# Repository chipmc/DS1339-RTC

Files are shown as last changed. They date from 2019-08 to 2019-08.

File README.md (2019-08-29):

# DS1339 RTC
DS1339 Real Time Clock Module
 
Created with EAGLE v9 - Information here including a free version - https://www.autodesk.com/products/eagle/overview

If you simply want to order this board, here is an OSHPark link: https://oshpark.com/shared_projects/rNxANV7V
 
This is a basic implementation of the Maxim DS1339 Real Time Clock.  The I2C and Interrupt pins are all presented on a 6-pin header.  There is also a 2-pin header to allow for other sources of battery backup power should you not chose to use the CR1225 coin cell on the back.

This is open source hardware, please feel free to use and improve according to the attached license.  This hardware was developed by See Insights LLC for a project sponsored by Jay Ham, Colorado State University - Thank You!

# Related Software Projects

The original library by Shridhar Rajagopal - https://github.com/sridharrajagopal/DSRTCLib

An adaptation of Shridhar's project I made for the Particle platform - https://github.com/chipmc/RTC-Watchdog

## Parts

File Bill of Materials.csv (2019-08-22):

Part | Value | Device | Package | Digikey | Description | DESCRIPTION | DIGI-KEY_PART_NUMBER | DIGI-KEY_PURCHASE_URL | MF | MP | PACKAGE | PROD_ID | SF_SKU | VALUE
CR1225 |  | BATTERY-12MM_SMD | BATTCON_12MM | EBR1225-ND | Battery - Single Cell |  |  |  |  |  |  | BATT-08044 | PRT-10592
J1 |  | CONN_06LOCK | 1X06_LOCK |  | Multi connection point. Often used as Generic Header-pin footprint for 0.1 inch spaced/style header connections
J2 |  | CONN_02 | 1X02 |  | Multi connection point. Often used as Generic Header-pin footprint for 0.1 inch spaced/style header connections
R1 | 4.7k | RESISTOR0805 | 0805 | 311-4.70KCRCT-ND | Generic Resistor Package
R2 | 4.7k | RESISTOR0805 | 0805 | 311-4.70KCRCT-ND | Generic Resistor Package
R3 | 10k | RESISTOR0805 | 0805 | 311-10.0KCRCT-ND | Generic Resistor Package
U1 | DS1339AU | DS1339AU | SOP65P490X110-8N | DS1339U-33+T&RCT-ND |  | Real Time Clock Serial 8-Pin uMAX | DS1339AU+-ND | https://www.digikey.com/product-detail/en/maxim-integrated/DS1339AU-/DS1339AU--ND/3440513 | Maxim Integrated | DS1339AU+ | &amp | MICRO | MAX-8 Maxim
Y1 | ECS-.327-6-17X-TR | ECS-.327-6-17X-TR | XTAL_ECS-.327-6-17X-TR | XC1307CT-ND | Crystal 4-SOJ, 5.50mm pitch | ECX-306X Series 32.768 kHz ±20 ppm 6 pF -40 to +85 °C SMT Tuning Fork Crystal | XC1307CT-ND | https://www.digikey.com/product-detail/en/ecs-inc/ECS-.327-6-17X-TR/XC1307CT-ND/827771 | ECS Inc. | ECS-.327-6-17X-TR | 4-4 ECS International

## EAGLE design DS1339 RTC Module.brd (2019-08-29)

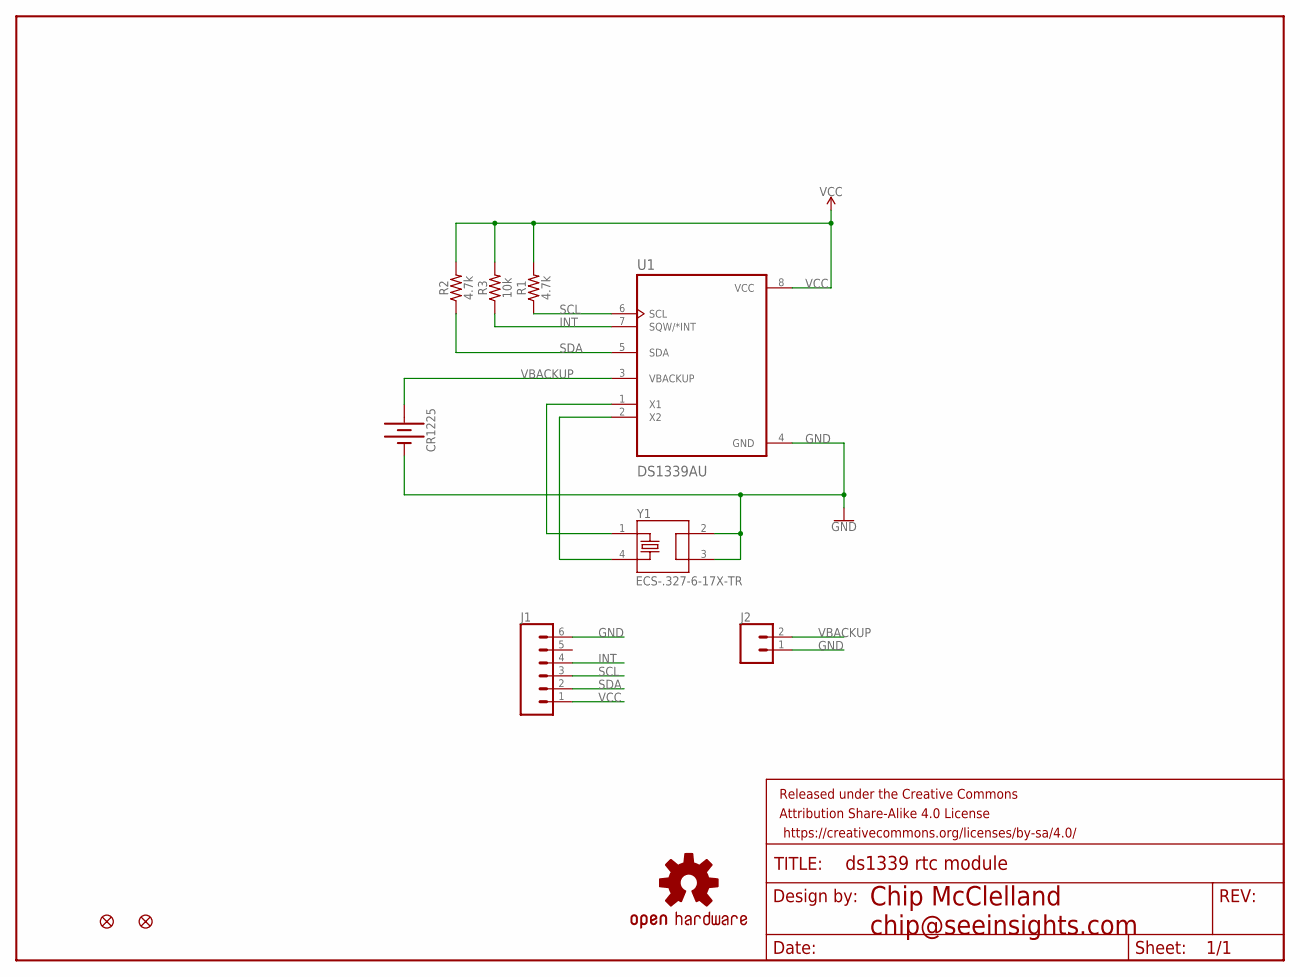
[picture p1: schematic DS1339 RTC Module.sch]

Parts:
CR1225: BATTERY-12MM_SMD; BATTCON_12MM
FD1, FD2: FIDUCIALUFIDUCIAL; FIDUCIAL-MICRO
FRAME1: FRAME-LETTER; CREATIVE_COMMONS
J1: CONN_06LOCK; 1X06_LOCK
J2: CONN_02; 1X02
LOGO1: OSHW-LOGOMINI; OSHW-LOGO-MINI
R1, R2: 4.7k; 0805
R3: 10k; 0805
U1: DS1339AU; SOP65P490X110-8N
Y1: ECS-.327-6-17X-TR; XTAL_ECS-.327-6-17X-TR

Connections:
GND: CR1225.GND (-), J1.6, J2.1, U1.4 (GND), Y1.2, Y1.3
INT: J1.4, R3.1, U1.7 (SQW/*INT)
unnamed: U1.1 (X1), Y1.1
unnamed: U1.2 (X2), Y1.4
SCL: J1.3, R1.1, U1.6 (SCL)
SDA: J1.2, R2.1, U1.5 (SDA)
VBACKUP: CR1225.PWR@2 (+), J2.2, U1.3 (VBACKUP)
VCC: J1.1, R1.2, R2.2, R3.2, U1.8 (VCC)

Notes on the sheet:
Chip McClelland chip@seeinsights.com

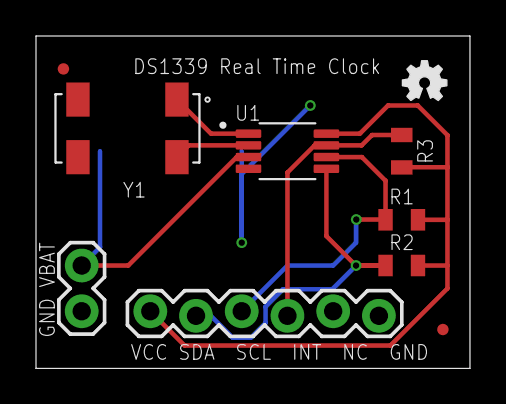
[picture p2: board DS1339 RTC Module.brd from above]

Board: 2 copper layers, 24.1 x 18.5 mm, 12 parts (1 on the bottom side), 8 nets.

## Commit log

2019-08-22 Updated for Publishing
    [DS1339 RTC Module.brd, DS1339 RTC Module.sch]
2019-08-22 Aesthetic Updates
    [DS1339 RTC Module.brd, DS1339 RTC Module.sch]
2019-08-22 Update DS1339 RTC Module.brd
    [DS1339 RTC Module.brd]
2019-08-22 Oops - Flipped VCC and GND on connector
    [DS1339 RTC Module.brd, DS1339 RTC Module.sch]
2019-08-22 Fine Tuned some routing
    [DS1339 RTC Module.brd]
2019-08-22 Added labels on the bottom too.
    [DS1339 RTC Module.brd]
2019-08-22 Added BOM and values
    [DS1339 RTC Module.brd, DS1339 RTC Module.csv, DS1339 RTC Module.sch]
2019-08-22 Rename DS1339 RTC Module.csv to Bill of Materials.csv
    [Bill of Materials.csv]

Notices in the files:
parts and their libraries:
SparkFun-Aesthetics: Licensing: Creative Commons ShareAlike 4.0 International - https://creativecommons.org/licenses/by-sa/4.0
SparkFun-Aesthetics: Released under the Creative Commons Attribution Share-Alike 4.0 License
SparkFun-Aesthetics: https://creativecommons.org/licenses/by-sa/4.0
